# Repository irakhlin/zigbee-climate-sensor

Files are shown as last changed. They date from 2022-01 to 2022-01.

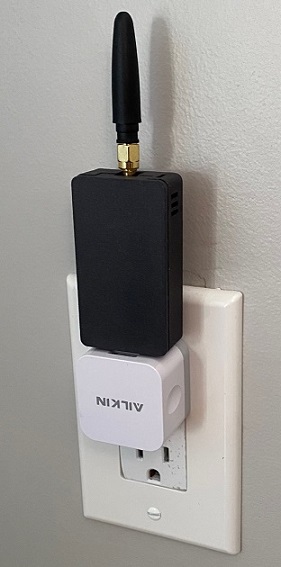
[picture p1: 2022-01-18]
docs/image2.jpg

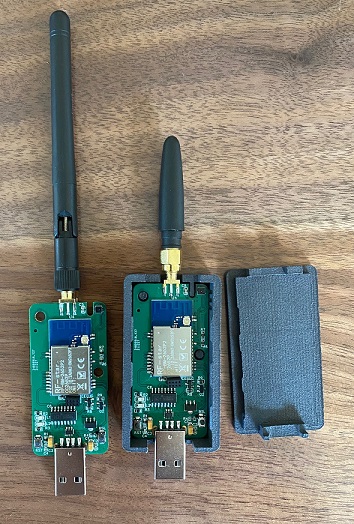
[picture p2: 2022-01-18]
docs/image3.jpg

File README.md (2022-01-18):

- [ClimateSense](#climatesense)
  * [Description](#description)
  * [Features](#features)
  * [Device Basics](#device-basics)
    + [Factory Reset](#factory-reset)
  * [Flashing Instructions](#flashing-instructions)
    + [Method 1: Preferred](#method-1--preferred)
    + [Method 2: If auto BSL is not working](#method-2--if-auto-bsl-is-not-working)
    + [Method 2b: GUI version but Windows only](#method-2b--gui-version-but-windows-only)
    + [Method 3: Worst case scenario](#method-3--worst-case-scenario)
  * [Setup](#setup)
    + [ZHA setup](#zha-setup)
        * [Additional ZHA docs:](#additional-zha-docs-)
  * [Zigbee2mqtt setup](#zigbee2mqtt-setup)

# ClimateSense

## Description

## Features

## Device Basics

 - Green LED:
	 - Blinks when device is either attempting to join a zigbee network or has not yet joined a zigbee network. 
	 - Blinking will stop when the device joins a network, will restart blinking if removed from the network.
- Red LED:
	 - This LED is meant as a locator LED, in case there are multiple devices in a location and there is a need to locate a specific one. It will be on during the initial configuration of the device.
	 -  After the device has joined a Zigbee network and been successfully interviewed home assistant will create an "on/off" switch entity for the device, this will allow to turn the LED on or off as desired.
- RST Button: (On left with USB pointing down)
	- Simple tap restarts the device, equivalent of unplugging and plugging back into power
- BSL Button: (On right with USB pointing down)
	- Can be used to boot device into boot loader mode
	- If device is joined to a network, holding down the BSL button for 10 seconds will factory reset the device. It is best to first remove the device from the coordinator in software as then the coordinator will send the proper reset command automatically and prevent the possibility of on the coordinator side. 

### Factory Reset
Method 1: 

## Flashing Instructions

### Method 1: Preferred
This board contains a small auto BSL circuit that allows the device to be put into bootloader mode automatically via toggling of the DTS and RTS pins on the UART chip. This option is already built into cc2538-bsl, the recommended utility for doing (windows and Linux compatible). [Link](https://github.com/JelmerT/cc2538-bsl)

The specific command line flag needed is "--bootloader-sonoff-usb". 

The following example will boot the device into boot loader mode, erase, write and verify the firmware for the device connected on COM6 (check control panel for the COM port number) using the firmware file 'climatesense1.0.hex'
``` 
python cc2538-bsl.py -ewv --bootloader-sonoff-usb -p COM6 climatesense1.0.hex
```
or on Linux..
```
python cc2538-bsl.py -ewv --bootloader-sonoff-usb -p /dev/ttyUSB0 climatesense1.0.hex
```
### Method 2: If auto BSL is not working
If the device is failing to enter boot loader mode automatically it can be done manually. 1. Before plugging in the device locate the button labeled "BSL" (bottom right if the USB port is pointing down).
2. Before plugging in the device hold down the BSL button, it must be held down as the device is plugged into the USB port.
3. Continue to hold the BSL button for 5-7 seconds after it has been inserted into USB.
4.  Proceed to flashing without the boot loader flag.
```
python cc2538-bsl.py -ewv -p /dev/ttyUSB0 imanz.climatesense1.0.hex
```

### Method 2b: GUI version but Windows only
Texas Instruments provide a windows GUI utility for performing the same process as in method 2, auto BSL however will not work like in method 1 so boot loader mode will need to be entered manually. Only really recommended if you are having some specific issue with cc2538-bsl.py. More information can be found [here](https://electrolama.com/radio-docs/flash-ti-flash-prog/)

### Method 3: Worst case scenario
The small black 8 pin connector allows access to the DEBUG pins on the CC2652p but the arrangement has been slightly modified for space. This method also requires a JTAG compatible device.
**TODO: add custom debugger board pin layout**
Links:
[JTag Flashing](https://electrolama.com/radio-docs/advanced/flash-jtag/)

## Setup
Depending on the home assistant installation type (docker, python native, supervised) the instructions to setup a basic Zigbee coordinator may be slightly different. There are two Zigbee integrations, zigbee2mqtt or ZHA ( built into HA), I personally use zigbee2mqtt installed from the "addon store" in a "fully suprvised hassio OS install", but have also tested in ZHA.

### ZHA setup
ZHA uses the concepts of "quirk" files which are used to help ZHA translate the devices specific "configurations" to proper properties. Before adding the device you must add a quirk directory, add the provided quirk and restart home assistant.

 1. Inside the Home Assistant configuration directory create a directory called custom_zha_quirks
```
cd /home/homeassistant/.homeassistant && mkdir custom_zha_quirks
```
2. Copy the provided quirk from converters/climatesense1.0.py to the directory and set correct permission
```
cd /home/homeassistant/.homeassistant/custom_zha_quirks
wget https://raw.githubusercontent.com/irakhlin/zigbee_climate_sensor/main/converters/climatesense1.0.py 
chown -R homeasistant:homeassistant /home/homeassistant/.homeassistant/custom_zha_quirks
chmod 644 /home/homeassistant/.homeassistant/custom_zha_quirks/climatesense1.0.py
```

3. Add the custom quirk directory path to your home assistant configuration file.
```
zha:
  enable_quirks: true
  custom_quirks_path: /home/homeassistant/.homeassistant/custom_zha_quirks
```
4. Restart home assistant
5. Proceed to add the device as normal in ZHA
6. After the device has finished the interview process all property entities may not be created because of the way ZHA handles the custom quirk. If you do not see temperature/humidity entities for the newly added device simply restart home assistant and they will be generated.

##### Additional ZHA docs:
[Home Assistant ZHA Documentation](https://www.home-assistant.io/integrations/zha/)
[ZHA Quirks](https://github.com/zigpy/zha-device-handlers#testing-quirks-in-development-in-docker-based-install)

## Zigbee2mqtt setup

Zigbee2mqtt uses a concept called herdsman converters, which are essentially the same idea as a ZHA quirk but written in javascript using their own zigbee library. A custom herdsman converter is provided in converters/climatesense1.0.js
1. Navigate to the zigbee2mqtt install directory and download the converter file
```
cd /opt/zigbee2mqtt
wget https://raw.githubusercontent.com/irakhlin/zigbee_climate_sensor/main/converters/climatesense1.0.js
chmod 755 /opt/zigbee2mqtt/climatesense1.0.js
```
2. Add the following to the configuration file for zigbee2mqtt
```
external_converters:
  - climatesense1.0.js
```
3. Restart and proceed to add device as normal

This may also be possible though the zigbee2mqtt GUI, see links below for more information.

[Zigbee2MQTT converter configuration](https://www.zigbee2mqtt.io/guide/configuration/more-config-options.html#external-converters)
[Herdsman converter](https://github.com/Koenkk/zigbee-herdsman-converters)

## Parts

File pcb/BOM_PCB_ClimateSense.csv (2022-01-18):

ID | Name | Designator | Footprint | Quantity | Manufacturer Part | Manufacturer | Supplier | Supplier Part | Price
1 | TS-1088C-02526 | BSL,RST | SW-SMD_L4.0-W2.9-P4.15-EH | 2 | TS-1088C-02526 | XUNPU | LCSC | C455279 | 0.057
2 | RF-BM-2652P1-V2F-26 COPY | U4 | RF-BM-2652P1-V2266 | 1 |  | RF-STAR | RF-STAR
3 | AZ1117CR2-3.3TRG1 | U2 | SOT-89_L4.5-W2.5-P1.50-LS4.2-BR | 1 | AZ1117CR2-3.3TRG1 | Diodes Incorporated | LCSC | C362111 | 0.284
4 | BWSMA-KE-P001 | RF1 | SMA-SMD_BWSMA-KE-P001 | 1 | BWSMA-KE-P001 | BAT WIRELESS | LCSC | C496550 | 0.525
5 | PM127V-12-08-H43 | DEBUG | HDR-TH_8P-P1.27-V-F-R2-C4-S1.27 | 1 | PM127V-12-08-H43 | XFCN | LCSC | C509139 | 0.155
6 | 10K | R1,R6,R7,R8,R9 | R0603 | 5 | ARG03FTC1002 | Viking Tech | LCSC | C217687 | 0.008
7 | 100 | R4 | R0603 | 1 | MR06X1000FTL | Huaxin S&T | LCSC | C327825 | 0.002
8 | 1K | R2,R3 | R0603 | 2 | ERJUP3F1001V | PANASONIC | LCSC | C491209 | 0.062
9 | 100nF | C2,C4,C5,C6 | C0603 | 4 | VJ0603Y104KXACW1BC | Vishay Intertech | LCSC | C161854 | 0.022
10 | USBLC6-2SC6 | D1 | SOT-23-6_L2.9-W1.6-P0.95-LS2.8-BR | 1 | USBLC6-2SC6 | STMicroelectronics | LCSC | C7519 | 0.258
11 | 10uF | C1 | CAP-SMD_L3.2-W1.6-R-RD | 1 | TAJA106K016RNJ | AVX | LCSC | C7171 | 0.114
12 | 22uF | C3 | CAP-SMD_L3.2-W1.6-R-RD | 1 | TAJA226K010RNJ | AVX | LCSC | C11366 | 0.138
13 | 0805G (Green) | L1 | LED0805-RD_GREEN | 1 | 0805G (Green) | KENTO | LCSC | C2297 | 0.014
14 | FC-2012HRK-620D | L2 | LED0805-RD_RED | 1 | FC-2012HRK-620D | NATIONSTAR | LCSC | C84256 | 0.013
15 | BC847C | Q1,Q2 | SOT-23-3_L2.9-W1.6-P1.90-LS2.8-BR | 2 | BC847C | Hottech | LCSC | C181141 | 0.011
16 | SHT35-DIS-B | S1 | DFN-8_L2.5-W2.5-P0.50-TL-EP | 1 | SHT35-DIS-B | Sensirion | LCSC | C90161 | 5.579
17 | CH340C | U1 | SOP-16_L10.0-W3.9-P1.27-LS6.0-BL | 1 | CH340C | WCH | LCSC | C84681 | 0.802
18 | USB-A-A/M Stick plate bent legs VinylPBT With a column | USB | USB-A-SMD_USB-A-1-TH | 1 | A/M Stick plate bent legs VinylPBT With a column | ValuePro | LCSC | C46394 | 0.092

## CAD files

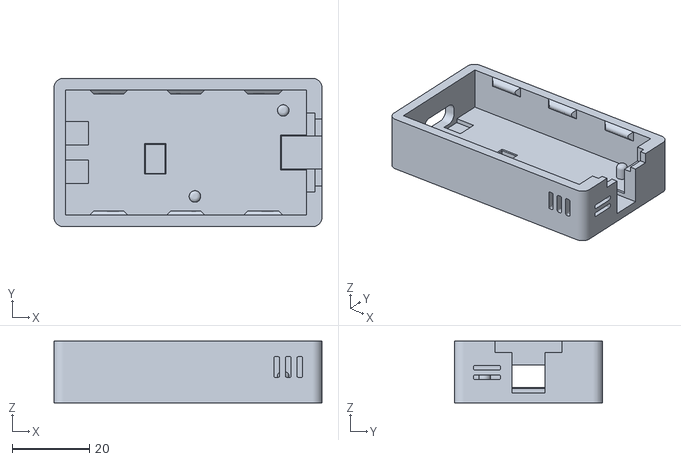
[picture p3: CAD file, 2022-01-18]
case/base.stl
69.5 x 38.5 x 16.0

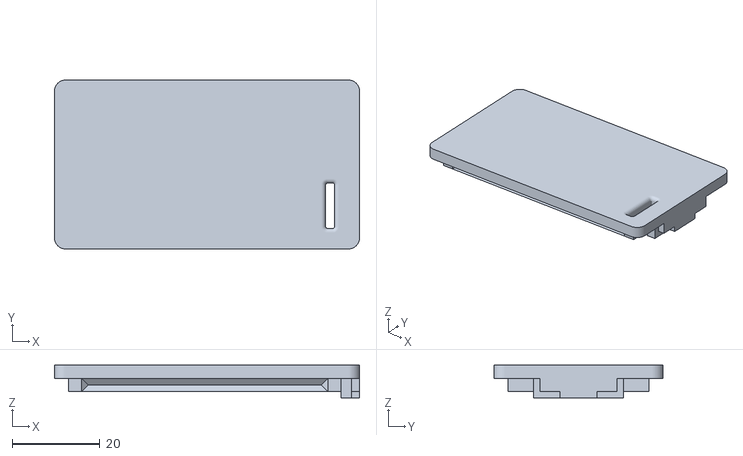
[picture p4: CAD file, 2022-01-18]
case/lid.stl
69.5 x 38.5 x 7.45

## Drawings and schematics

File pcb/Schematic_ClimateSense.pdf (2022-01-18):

## RF-BM-2652P2

## RF-BM-2652P1

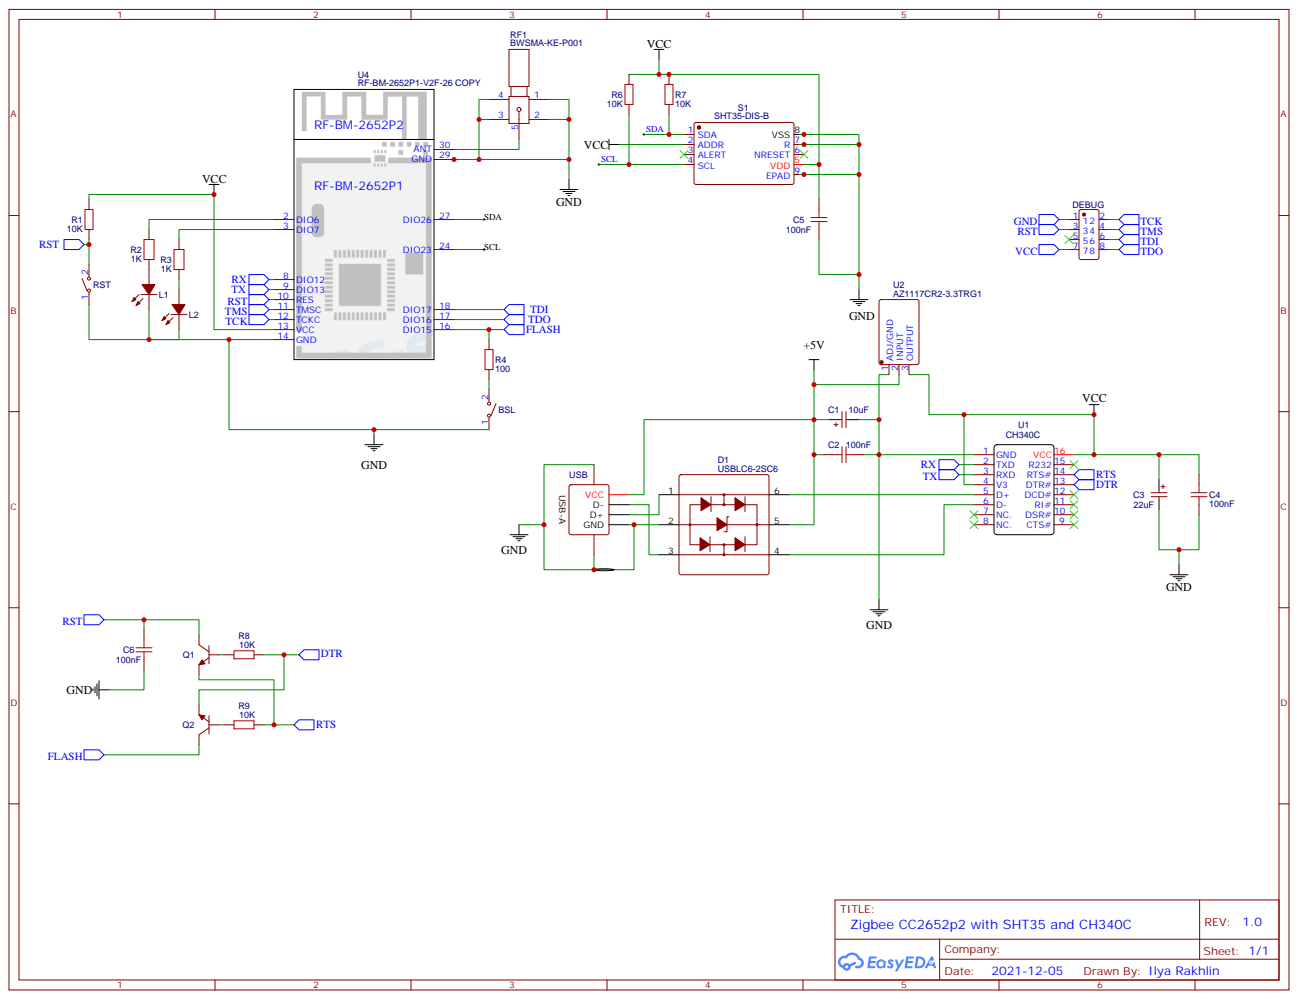
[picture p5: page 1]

Drawn By: Ilya Rakhlin

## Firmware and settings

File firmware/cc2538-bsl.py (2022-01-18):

#!/usr/bin/env python3

# Copyright (c) 2014, Jelmer Tiete <jelmer@tiete.be>.
# All rights reserved.
#
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
# Implementation based on stm32loader by Ivan A-R <ivan@tuxotronic.org>

# Serial boot loader over UART for CC13xx / CC2538 / CC26xx
# Based on the info found in TI's swru333a.pdf (spma029.pdf)
#
# Bootloader only starts if no valid image is found or if boot loader
# backdoor is enabled.
# Make sure you don't lock yourself out!! (enable backdoor in your firmware)
# More info at https://github.com/JelmerT/cc2538-bsl

from subprocess import Popen, PIPE

import sys
import getopt
import glob
import time
import os
import struct
import binascii
import traceback

try:
    import magic
    magic.from_file
    have_magic = True
except (ImportError, AttributeError):
    have_magic = False

try:
    from intelhex import IntelHex
    have_hex_support = True
except ImportError:
    have_hex_support = False

# version
__version__ = "2.1"

# Verbose level
QUIET = 5

try:
    import serial
except ImportError:
    print('{} requires the Python serial library'.format(sys.argv[0]))
    print('Please install it with:')
    print('')
    print('   pip3 install pyserial')
    sys.exit(1)


def mdebug(level, message, attr='\n'):
    if QUIET >= level:
        print(message, end=attr, file=sys.stderr)

# Takes chip IDs (obtained via Get ID command) to human-readable names
CHIP_ID_STRS = {0xb964: 'CC2538',
                0xb965: 'CC2538'
                }

RETURN_CMD_STRS = {0x40: 'Success',
                   0x41: 'Unknown command',
                   0x42: 'Invalid command',
                   0x43: 'Invalid address',
                   0x44: 'Flash fail'
                   }

COMMAND_RET_SUCCESS = 0x40
COMMAND_RET_UNKNOWN_CMD = 0x41
COMMAND_RET_INVALID_CMD = 0x42
COMMAND_RET_INVALID_ADR = 0x43
COMMAND_RET_FLASH_FAIL = 0x44


class CmdException(Exception):
    pass


class FirmwareFile(object):
    HEX_FILE_EXTENSIONS = ('hex', 'ihx', 'ihex')

    def __init__(self, path):
        """
        Read a firmware file and store its data ready for device programming.

        This class will try to guess the file type if python-magic is available.

        If python-magic indicates a plain text file, and if IntelHex is
        available, then the file will be treated as one of Intel HEX format.

        In all other cases, the file will be treated as a raw binary file.

        In both cases, the file's contents are stored in bytes for subsequent
        usage to program a device or to perform a crc check.

        Parameters:
            path -- A str with the path to the firmware file.

        Attributes:
            bytes: A bytearray with firmware contents ready to send to the
            device
        """
        self._crc32 = None
        firmware_is_hex = False

        if have_magic:
            file_type = magic.from_file(path, mime=True)

            if file_type == 'text/plain':
                firmware_is_hex = True
                mdebug(5, "Firmware file: Intel Hex")
            elif file_type == 'application/octet-stream':
                mdebug(5, "Firmware file: Raw Binary")
            else:
                error_str = "Could not determine firmware type. Magic " \
                            "indicates '%s'" % (file_type)
                raise CmdException(error_str)
        else:
            if os.path.splitext(path)[1][1:] in self.HEX_FILE_EXTENSIONS:
                firmware_is_hex = True
                mdebug(5, "Your firmware looks like an Intel Hex file")
            else:
                mdebug(5, "Cannot auto-detect firmware filetype: Assuming .bin")

            mdebug(10, "For more solid firmware type auto-detection, install "
                       "python-magic.")
            mdebug(10, "Please see the readme for more details.")

        if firmware_is_hex:
            if have_hex_support:
                self.bytes = bytearray(IntelHex(path).tobinarray())
                return
            else:
                error_str = "Firmware is Intel Hex, but the IntelHex library " \
                            "could not be imported.\n" \
                            "Install IntelHex in site-packages or program " \
                            "your device with a raw binary (.bin) file.\n" \
                            "Please see the readme for more details."
                raise CmdException(error_str)

        with open(path, 'rb') as f:
            self.bytes = bytearray(f.read())

    def crc32(self):
        """
        Return the crc32 checksum of the firmware image

        Return:
            The firmware's CRC32, ready for comparison with the CRC
            returned by the ROM bootloader's COMMAND_CRC32
        """
        if self._crc32 == None:
            self._crc32 = binascii.crc32(bytearray(self.bytes)) & 0xffffffff

        return self._crc32


class CommandInterface(object):

    ACK_BYTE = 0xCC
    NACK_BYTE = 0x33

    def open(self, aport=None, abaudrate=500000):
        # Try to create the object using serial_for_url(), or fall back to the
        # old serial.Serial() where serial_for_url() is not supported.
        # serial_for_url() is a factory class and will return a different
        # object based on the URL. For example serial_for_url("/dev/tty.<xyz>")
        # will return a serialposix.Serial object for Ubuntu or Mac OS;
        # serial_for_url("COMx") will return a serialwin32.Serial oject for Windows OS.
        # For that reason, we need to make sure the port doesn't get opened at
        # this stage: We need to set its attributes up depending on what object
        # we get.
        try:
            self.sp = serial.serial_for_url(aport, do_not_open=True, timeout=10, write_timeout=10)
        except AttributeError:
            self.sp = serial.Serial(port=None, timeout=10, write_timeout=10)
            self.sp.port = aport

        if ((os.name == 'nt' and isinstance(self.sp, serial.serialwin32.Serial)) or \
           (os.name == 'posix' and isinstance(self.sp, serial.serialposix.Serial))):
            self.sp.baudrate=abaudrate        # baudrate
            self.sp.bytesize=8                # number of databits
            self.sp.parity=serial.PARITY_NONE # parity
            self.sp.stopbits=1                # stop bits
            self.sp.xonxoff=0                 # s/w (XON/XOFF) flow control
            self.sp.rtscts=0                  # h/w (RTS/CTS) flow control
            self.sp.timeout=0.5               # set the timeout value

        self.sp.open()

    def invoke_bootloader(self, dtr_active_high=False, inverted=False, sonoff_usb=False):
        # Use the DTR and RTS lines to control bootloader and the !RESET pin.
        # This can automatically invoke the bootloader without the user
        # having to toggle any pins.
        #
        # If inverted is False (default):
        # DTR: connected to the bootloader pin
        # RTS: connected to !RESET
        # If inverted is True, pin connections are the other way round
        if inverted:
            set_bootloader_pin = self.sp.setRTS
            set_reset_pin = self.sp.setDTR
        else:
            set_bootloader_pin = self.sp.setDTR
            set_reset_pin = self.sp.setRTS

        if sonoff_usb:
            mdebug(5,'sonoff')
            # this bootloader toggle is added specifically for the
            # ITead Sonoff Zigbee 3.0 USB Dongle. This dongle has an odd
            # connection between RTS DTR and reset and IO15 (imply gate):
            # DTR  RTS  |  RST  IO15
            # 1     1   |   1    1
            # 0     0   |   1    1
            # 1     0   |   0    1
            # 0     1   |   1    0
            set_bootloader_pin(0)
            set_reset_pin(1)

            set_bootloader_pin(1)
            set_reset_pin(0)
        else:
            set_bootloader_pin(1 if not dtr_active_high else 0)
            set_reset_pin(0)
            set_reset_pin(1)

            set_reset_pin(0)
            # Make sure the pin is still asserted when the chip
            # comes out of reset. This fixes an issue where
            # there wasn't enough delay here on Mac.
            time.sleep(0.002)
            set_bootloader_pin(0 if not dtr_active_high else 1)

        # Some boards have a co-processor that detects this sequence here and
        # then drives the main chip's BSL enable and !RESET pins. Depending on
        # board design and co-processor behaviour, the !RESET pin may get
        # asserted after we have finished the sequence here. In this case, we
        # need a small delay so as to avoid trying to talk to main chip before
        # it has actually entered its bootloader mode.
        #
        # See contiki-os/contiki#1533
        time.sleep(0.1)

    def close(self):
        self.sp.close()

    def _wait_for_ack(self, info="", timeout=1):
        stop = time.time() + timeout
        got = bytearray(2)
        while got[-2] != 00 or got[-1] not in (CommandInterface.ACK_BYTE,
                                               CommandInterface.NACK_BYTE):
            got += self._read(1)
            if time.time() > stop:
                raise CmdException("Timeout waiting for ACK/NACK after '%s'"
                                   % (info,))

        # Our bytearray's length is: 2 initial bytes + 2 bytes for the ACK/NACK
        # plus a possible N-4 additional (buffered) bytes
        mdebug(10, "Got %d additional bytes before ACK/NACK" % (len(got) - 4,))

        # wait for ask
        ask = got[-1]

        if ask == CommandInterface.ACK_BYTE:
            # ACK
            return 1
        elif ask == CommandInterface.NACK_BYTE:
            # NACK
            mdebug(10, "Target replied with a NACK during %s" % info)
            return 0

        # Unknown response
        mdebug(10, "Unrecognised response 0x%x to %s" % (ask, info))
        return 0

    def _encode_addr(self, addr):
        byte3 = (addr >> 0) & 0xFF
        byte2 = (addr >> 8) & 0xFF
        byte1 = (addr >> 16) & 0xFF
        byte0 = (addr >> 24) & 0xFF
        return bytes([byte0, byte1, byte2, byte3])

    def _decode_addr(self, byte0, byte1, byte2, byte3):
        return ((byte3 << 24) | (byte2 << 16) | (byte1 << 8) | (byte0 << 0))

    def _calc_checks(self, cmd, addr, size):
        return ((sum(bytearray(self._encode_addr(addr))) +
                 sum(bytearray(self._encode_addr(size))) +
                 cmd) & 0xFF)

    def _write(self, data, is_retry=False):
        if type(data) == int:
            assert data < 256
            goal = 1
            written = self.sp.write(bytes([data]))
        elif type(data) == bytes or type(data) == bytearray:
            goal = len(data)
            written = self.sp.write(data)
        else:
            raise CmdException("Internal Error. Bad data type: {}"
                               .format(type(data)))

        if written < goal:
            mdebug(10, "*** Only wrote {} of target {} bytes"
                   .format(written, goal))
            if is_retry and written == 0:
                raise CmdException("Failed to write data on the serial bus")
            mdebug(10, "*** Retrying write for remainder")
            if type(data) == int:
                return self._write(data, is_retry=True)
            else:
                return self._write(data[written:], is_retry=True)

    def _read(self, length):
        return bytearray(self.sp.read(length))

    def sendAck(self):
        self._write(0x00)
        self._write(0xCC)
        return

    def sendNAck(self):
        self._write(0x00)
        self._write(0x33)
        return

    def receivePacket(self):
        # stop = time.time() + 5
        # got = None
        # while not got:
        got = self._read(2)
        #     if time.time() > stop:
        #         break

        # if not got:
        #     raise CmdException("No response to %s" % info)

        size = got[0]  # rcv size
        chks = got[1]  # rcv checksum
        data = bytearray(self._read(size - 2))  # rcv data

        mdebug(10, "*** received %x bytes" % size)
        if chks == sum(data) & 0xFF:
            self.sendAck()
            return data
        else:
            self.sendNAck()
            # TODO: retry receiving!
            raise CmdException("Received packet checksum error")
            return 0

    def sendSynch(self):
        cmd = 0x55

        # flush serial input buffer for first ACK reception
        self.sp.flushInput()

        mdebug(10, "*** sending synch sequence")
        self._write(cmd)  # send U
        self._write(cmd)  # send U
        return self._wait_for_ack("Synch (0x55 0x55)", 2)

    def checkLastCmd(self):
        stat = self.cmdGetStatus()
        if not (stat):
            raise CmdException("No response from target on status request. "
                               "(Did you disable the bootloader?)")

        if stat[0] == COMMAND_RET_SUCCESS:
            mdebug(10, "Command Successful")
            return 1
        else:
            stat_str = RETURN_CMD_STRS.get(stat[0], None)
            if stat_str == None:
                mdebug(0, "Warning: unrecognized status returned "
                          "0x%x" % stat[0])
            else:
                mdebug(0, "Target returned: 0x%x, %s" % (stat[0], stat_str))
            return 0

    def cmdPing(self):
        cmd = 0x20
        lng = 3

        self._write(lng)  # send size
        self._write(cmd)  # send checksum
        self._write(cmd)  # send data

        mdebug(10, "*** Ping command (0x20)")
        if self._wait_for_ack("Ping (0x20)"):
            return self.checkLastCmd()

    def cmdReset(self):
        cmd = 0x25
        lng = 3

        self._write(lng)  # send size
        self._write(cmd)  # send checksum
        self._write(cmd)  # send data

        mdebug(10, "*** Reset command (0x25)")
        if self._wait_for_ack("Reset (0x25)"):
            return 1

    def cmdGetChipId(self):
        cmd = 0x28
        lng = 3

        self._write(lng)  # send size
        self._write(cmd)  # send checksum
        self._write(cmd)  # send data

        mdebug(10, "*** GetChipId command (0x28)")
        if self._wait_for_ack("Get ChipID (0x28)"):
            # 4 byte answ, the 2 LSB hold chip ID
            version = self.receivePacket()
            if self.checkLastCmd():
                assert len(version) == 4, ("Unreasonable chip "
                                           "id: %s" % repr(version))
                mdebug(10, "    Version 0x%02X%02X%02X%02X" % tuple(version))
                chip_id = (version[2] << 8) | version[3]
                return chip_id
            else:
                raise CmdException("GetChipID (0x28) failed")

    def cmdGetStatus(self):
        cmd = 0x23
        lng = 3

        self._write(lng)  # send size
        self._write(cmd)  # send checksum
        self._write(cmd)  # send data

        mdebug(10, "*** GetStatus command (0x23)")
        if self._wait_for_ack("Get Status (0x23)"):
            stat = self.receivePacket()
            return stat

    def cmdSetXOsc(self):
        cmd = 0x29
        lng = 3

        self._write(lng)  # send size
        self._write(cmd)  # send checksum
        self._write(cmd)  # send data

        mdebug(10, "*** SetXOsc command (0x29)")
        if self._wait_for_ack("SetXOsc (0x29)"):
            return 1
            # UART speed (needs) to be changed!

    def cmdRun(self, addr):
        cmd = 0x22
        lng = 7

        self._write(lng)  # send length
        self._write(self._calc_checks(cmd, addr, 0))  # send checksum
        self._write(cmd)  # send cmd
        self._write(self._encode_addr(addr))  # send addr

        mdebug(10, "*** Run command(0x22)")
        return 1

    def cmdEraseMemory(self, addr, size):
        cmd = 0x26
        lng = 11

        self._write(lng)  # send length
        self._write(self._calc_checks(cmd, addr, size))  # send checksum
        self._write(cmd)  # send cmd
        self._write(self._encode_addr(addr))  # send addr
        self._write(self._encode_addr(size))  # send size

        mdebug(10, "*** Erase command(0x26)")
        if self._wait_for_ack("Erase memory (0x26)", 10):
            return self.checkLastCmd()

    def cmdBankErase(self):
        cmd = 0x2C
        lng = 3

        self._write(lng)  # send length
        self._write(cmd)  # send checksum
        self._write(cmd)  # send cmd

        mdebug(10, "*** Bank Erase command(0x2C)")
        if self._wait_for_ack("Bank Erase (0x2C)", 10):
            return self.checkLastCmd()

    def cmdCRC32(self, addr, size):
        cmd = 0x27
        lng = 11

        self._write(lng)  # send length
        self._write(self._calc_checks(cmd, addr, size))  # send checksum
        self._write(cmd)  # send cmd
        self._write(self._encode_addr(addr))  # send addr
        self._write(self._encode_addr(size))  # send size

        mdebug(10, "*** CRC32 command(0x27)")
        if self._wait_for_ack("Get CRC32 (0x27)", 1):
            crc = self.receivePacket()
            if self.checkLastCmd():
                return self._decode_addr(crc[3], crc[2], crc[1], crc[0])

    def cmdCRC32CC26xx(self, addr, size):
        cmd = 0x27
        lng = 15

        self._write(lng)  # send length
        self._write(self._calc_checks(cmd, addr, size))  # send checksum
        self._write(cmd)  # send cmd
        self._write(self._encode_addr(addr))  # send addr
        self._write(self._encode_addr(size))  # send size
        self._write(self._encode_addr(0x00000000))  # send number of reads

        mdebug(10, "*** CRC32 command(0x27)")
        if self._wait_for_ack("Get CRC32 (0x27)", 1):
            crc = self.receivePacket()
            if self.checkLastCmd():
                return self._decode_addr(crc[3], crc[2], crc[1], crc[0])

    def cmdDownload(self, addr, size):
        cmd = 0x21
        lng = 11

        if (size % 4) != 0:  # check for invalid data lengths
            raise Exception('Invalid data size: %i. '
                            'Size must be a multiple of 4.' % size)

        self._write(lng)  # send length
        self._write(self._calc_checks(cmd, addr, size))  # send checksum
        self._write(cmd)  # send cmd
        self._write(self._encode_addr(addr))  # send addr
        self._write(self._encode_addr(size))  # send size

        mdebug(10, "*** Download command (0x21)")
        if self._wait_for_ack("Download (0x21)", 2):
            return self.checkLastCmd()

    def cmdSendData(self, data):
        cmd = 0x24
        lng = len(data)+3
        # TODO: check total size of data!! max 252 bytes!

        self._write(lng)  # send size
        self._write((sum(bytearray(data))+cmd) & 0xFF)  # send checksum
        self._write(cmd)  # send cmd
        self._write(bytearray(data))  # send data

        mdebug(10, "*** Send Data (0x24)")
        if self._wait_for_ack("Send data (0x24)", 10):
            return self.checkLastCmd()

    def cmdMemRead(self, addr):  # untested
        cmd = 0x2A
        lng = 8

        self._write(lng)  # send length
        self._write(self._calc_checks(cmd, addr, 4))  # send checksum
        self._write(cmd)  # send cmd
        self._write(self._encode_addr(addr))  # send addr
        self._write(4)  # send width, 4 bytes

        mdebug(10, "*** Mem Read (0x2A)")
        if self._wait_for_ack("Mem Read (0x2A)", 1):
            data = self.receivePacket()
            if self.checkLastCmd():
                # self._decode_addr(ord(data[3]),
                #                   ord(data[2]),ord(data[1]),ord(data[0]))
                return data

    def cmdMemReadCC26xx(self, addr):
        cmd = 0x2A
        lng = 9

        self._write(lng)  # send length
        self._write(self._calc_checks(cmd, addr, 2))  # send checksum
        self._write(cmd)  # send cmd
        self._write(self._encode_addr(addr))  # send addr
        self._write(1)  # send width, 4 bytes
        self._write(1)  # send number of reads

        mdebug(10, "*** Mem Read (0x2A)")
        if self._wait_for_ack("Mem Read (0x2A)", 1):
            data = self.receivePacket()
            if self.checkLastCmd():
                return data

    def cmdMemWrite(self, addr, data, width):
        if width != len(data):
            raise ValueError("width does not match len(data)")
        if width != 1 and width != 4:
            raise ValueError("width must be 1 or 4")

        cmd = 0x2B
        lng = 8 + len(data)

        content = (
            bytearray([cmd])
            + self._encode_addr(addr)
            + bytearray([1 if (width == 4) else 0])
            + bytearray(data)
        )

        self._write(lng)  # send length
        self._write(sum(content) & 0xFF)  # send checksum
        self._write(content)

        mdebug(10, "*** Mem write (0x2B)")
        if self._wait_for_ack("Mem Write (0x2B)", 2):
            return self.checkLastCmd()
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
